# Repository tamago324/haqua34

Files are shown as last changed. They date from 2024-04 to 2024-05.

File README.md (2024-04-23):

# haqua34

* gku34 を割ったキーボード
* 割った以外は gku34 と同じ
    * 狭ピッチ
    * キーピッチが縦17mmx横18mm
    * KiCad 6 で作成
    * [horizon プラグイン](https://github.com/skarrmann/horizon/blob/5833ec133d5f8fa4f3824622efd5dbfc89d797ec/kicad-plugins/horizon-board-producer-plugin.py)を使ってボトムプレートを生成
    * choc v1 と Lofree switch 対応

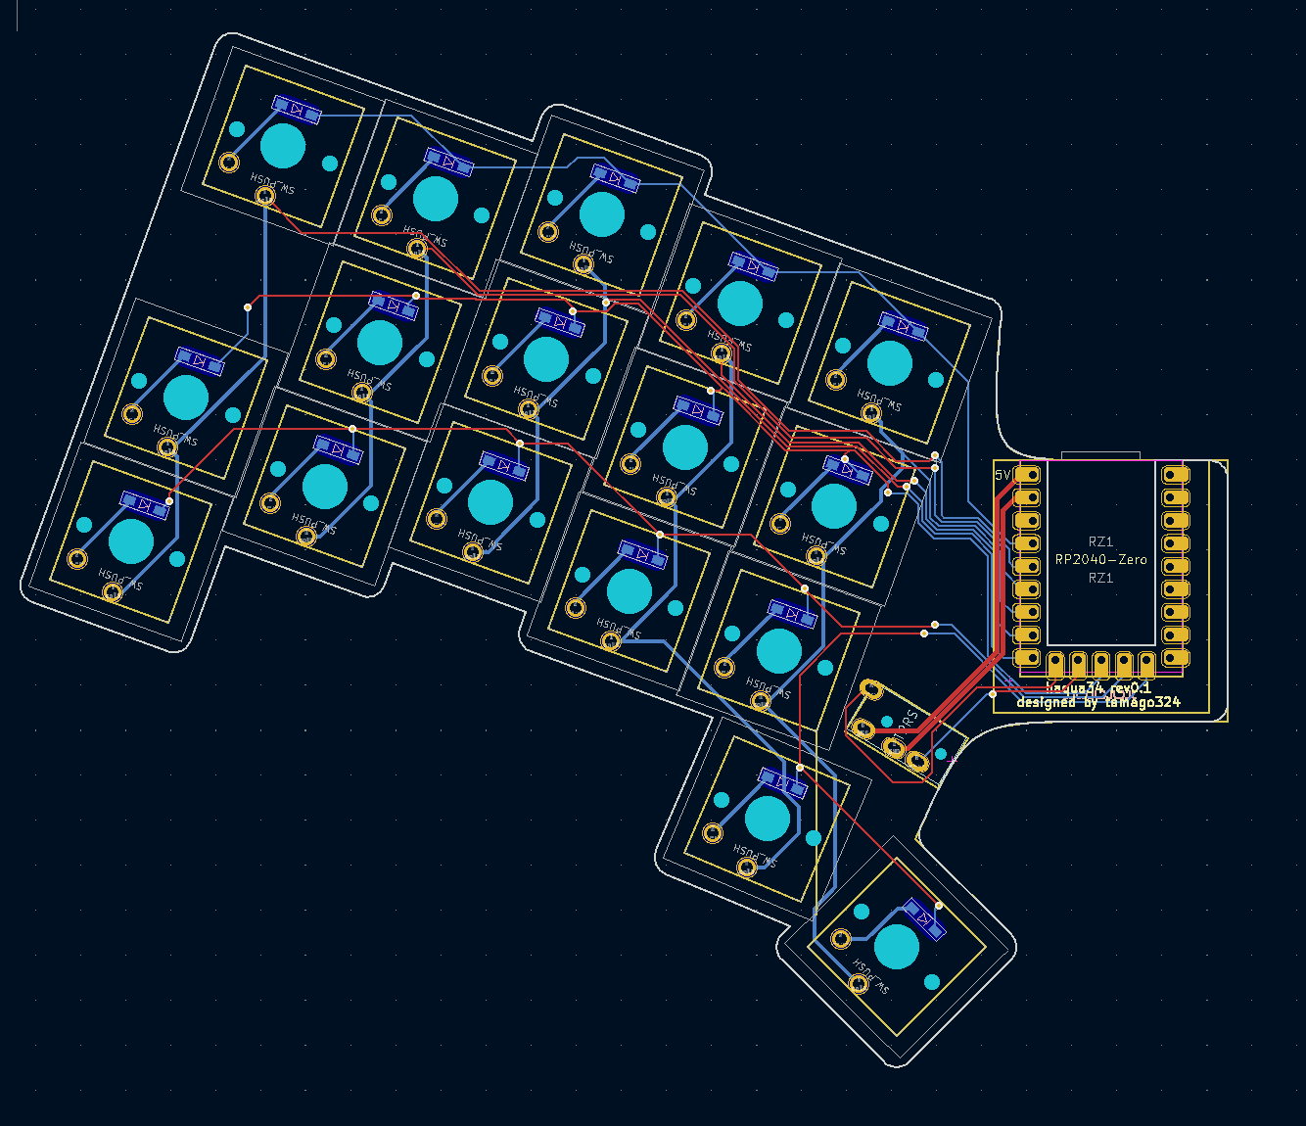
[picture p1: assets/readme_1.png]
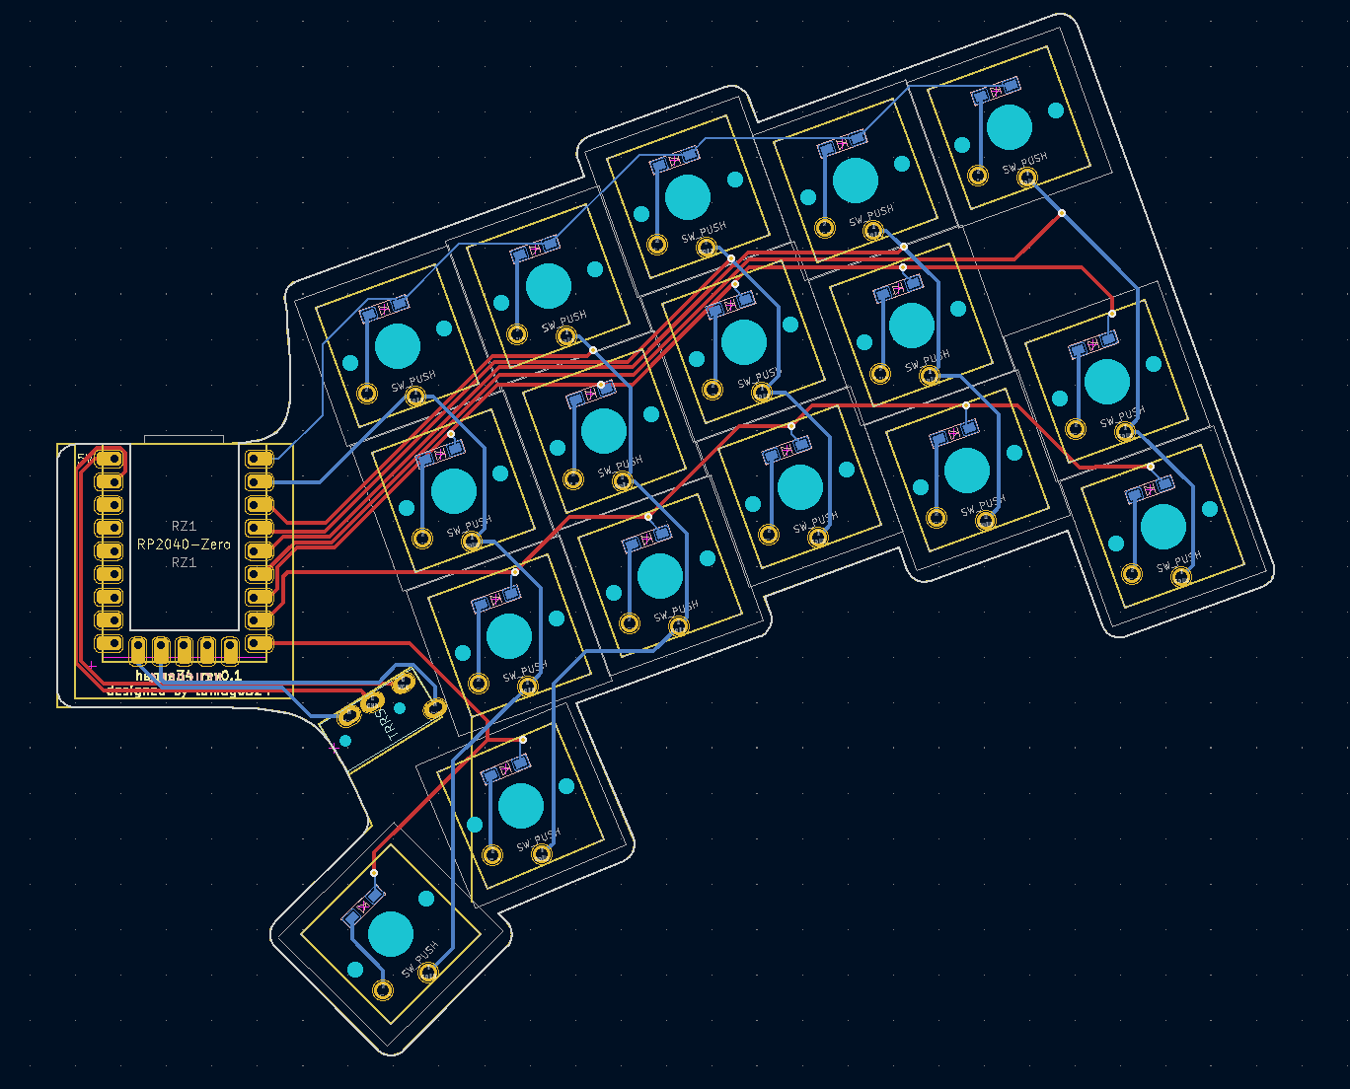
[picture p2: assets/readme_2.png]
|||
|---|---|
|left|right|

## Firmware

[keyboard-firmwares](https://github.com/tamago324/keyboard-firmwares) 内の `keybaords/haqua34`

## LICENSE

<br />この 作品 は <a rel="license" href="http://creativecommons.org/licenses/by-nc/4.0/">クリエイティブ・コモンズ 表示 - 非営利 4.0 国際 ライセンス</a>の下に提供されています。

> 表示 — あなたは 適切なクレジットを表示し、ライセンスへのリンクを提供し、変更があったらその旨を示さなければなりません。これらは合理的であればどのような方法で行っても構いませんが、許諾者があなたやあなたの利用行為を支持していると示唆するような方法は除きます。
>
> 非営利 — あなたは営利目的でこの資料を利用してはなりません。

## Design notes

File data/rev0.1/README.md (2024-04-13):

## 発注するとき (JLCPCB)

* 基板
  * main_pcb (メイン基板)
    * left: `gerbers/left_main_pcb/haqua34_left_134.025522x114.635239mm_for_JLCPCB.zip`
      * PCB Thickness: 1.6mm
      * Remove Order Number: Specify a location
    * right: `gerbers/right_main_pcb/haqua34_right_134.025517x114.635239mm_for_JLCPCB.zip`
      * PCB Thickness: 1.6mm
      * Remove Order Number: Specify a location
  * bottom_plate (ボトムプレート)
    * left: `gerbers/left_bottom_plate/haqua34_left-bottom-plate_134.025522x114.635239mm_for_JLCPCB.zip`
      * PCB Thickness: 1.6mm
      * Remove Order Number: Specify a location
    * right: `gerbers/right_bottom_plate/haqua34_right-bottom-plate_134.025517x114.635239mm_for_JLCPCB.zip`
      * PCB Thickness: 1.6mm
      * Remove Order Number: Specify a location
* トッププレート
  * left: `stl/top_plate_left.stl`
    * 3D Technology: MJF(Nylon)
    * Material: PA12-HP Nylon
    * Color: Black
  * right: `stl/top_plate_right.stl`
    * 3D Technology: MJF(Nylon)
    * Material: PA12-HP Nylon
    * Color: Black

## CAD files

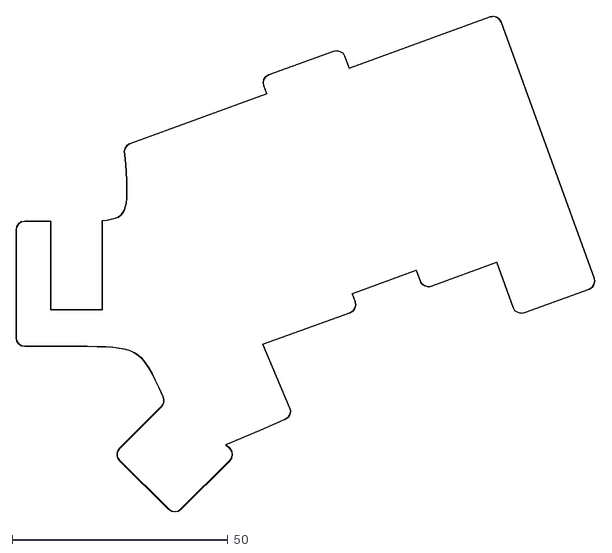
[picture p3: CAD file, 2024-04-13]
data/rev0.1/dxf/pcb_edge_right.dxf
134.3 x 115.0

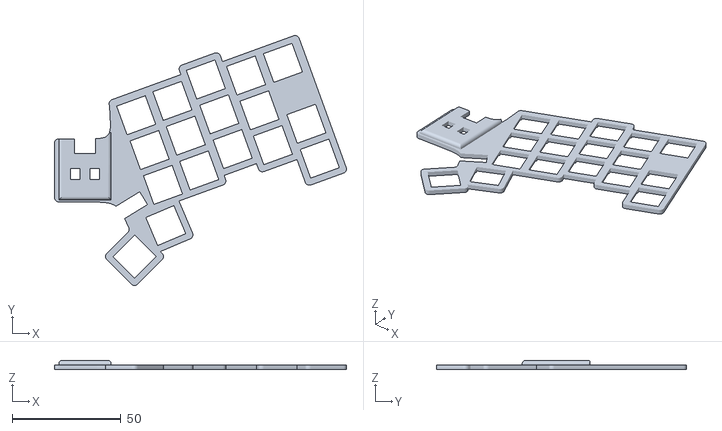
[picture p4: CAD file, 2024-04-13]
data/rev0.1/stl/top_plate_right.stl
134.0 x 114.8 x 4.20

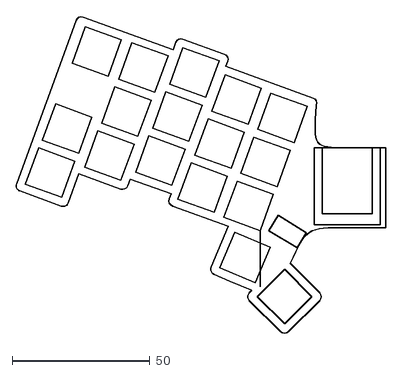
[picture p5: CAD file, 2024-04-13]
data/rev0.1/dxf/pcb_support_left.dxf
134.1 x 115.2

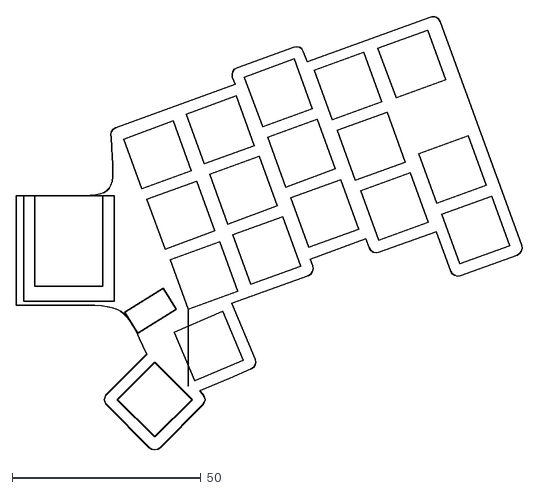
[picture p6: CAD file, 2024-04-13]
data/rev0.1/dxf/pcb_support_right.dxf
134.3 x 115.0

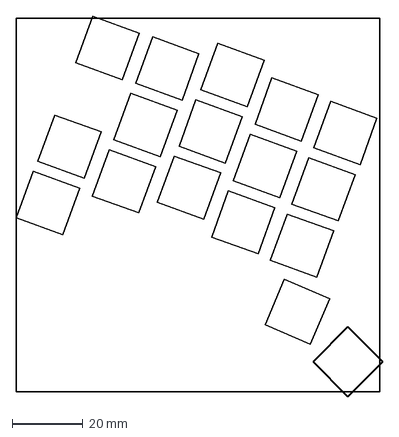
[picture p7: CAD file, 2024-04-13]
data/rev0.1/dxf/layout-base.dxf
103.9 x 107.8 mm

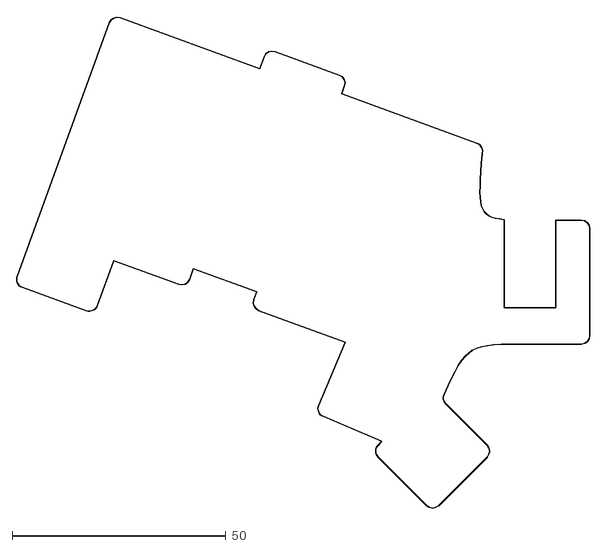
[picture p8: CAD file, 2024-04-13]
data/rev0.1/dxf/pcb_edge_left.dxf
134.1 x 115.2

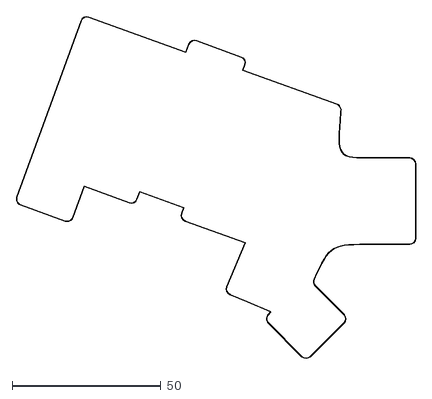
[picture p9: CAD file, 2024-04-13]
data/rev0.1/dxf/pcb_bottom_edge_left.dxf
134.1 x 115.2

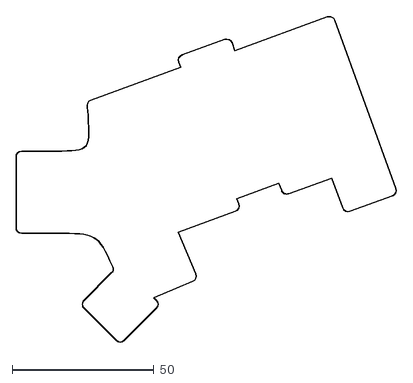
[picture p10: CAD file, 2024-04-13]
data/rev0.1/dxf/pcb_bottom_edge_right.dxf
134.3 x 115.0

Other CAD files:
data/rev0.1/stl/top_plate_left.stl

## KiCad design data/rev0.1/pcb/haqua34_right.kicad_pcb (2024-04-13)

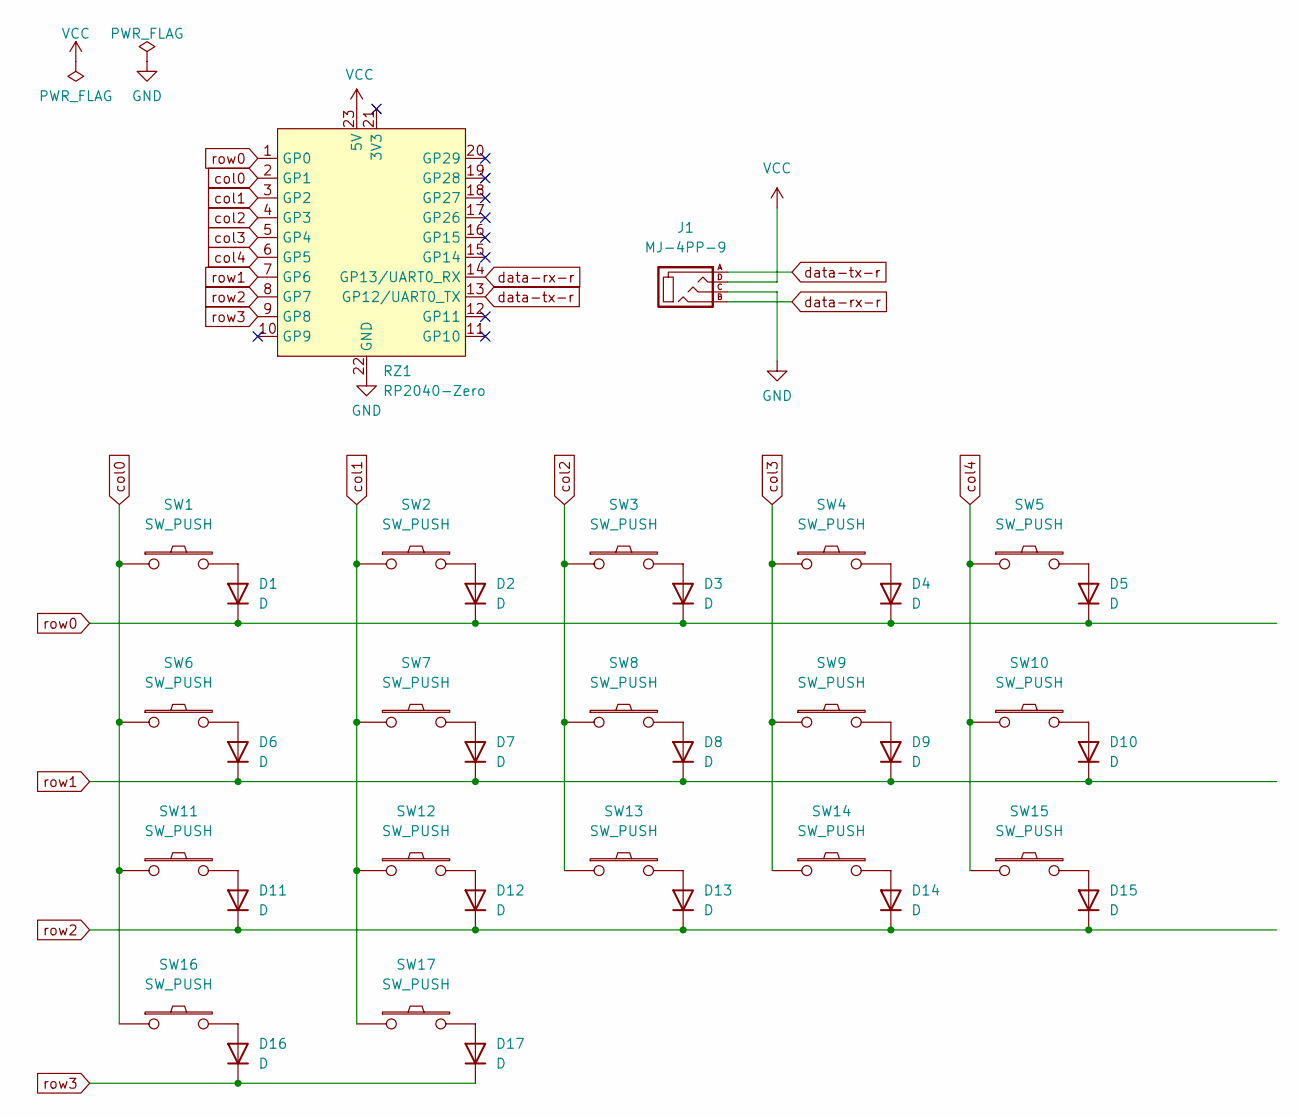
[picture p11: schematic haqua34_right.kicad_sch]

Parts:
D1, D2, D3, D4, D5, D6, D7, D8, D9, D10, D11, D12, D13, D14, D15, D16, D17: D; Diode_SMD
J1: MJ-4PP-9
RZ1: RP2040-Zero
SW1, SW2, SW3, SW4, SW5, SW6, SW7, SW8, SW9, SW10, SW11, SW12, SW13, SW14, SW15, SW16, SW17: SW_PUSH; SW_Choc_V2

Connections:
GND: J1.C, RZ1.22 (GND)
unnamed: D1.2 (A), SW1.2
unnamed: D2.2 (A), SW2.2
unnamed: D3.2 (A), SW3.2
unnamed: D4.2 (A), SW4.2
unnamed: D5.2 (A), SW5.2
unnamed: D6.2 (A), SW6.2
unnamed: D7.2 (A), SW7.2
unnamed: D8.2 (A), SW8.2
unnamed: D9.2 (A), SW9.2
unnamed: D10.2 (A), SW10.2
unnamed: D11.2 (A), SW11.2
unnamed: D12.2 (A), SW12.2
unnamed: D13.2 (A), SW13.2
unnamed: D14.2 (A), SW14.2
unnamed: D15.2 (A), SW15.2
unnamed: D16.2 (A), SW16.2
unnamed: D17.2 (A), SW17.2
VCC: J1.D, RZ1.23 (5V)
col0: RZ1.2 (GP1), SW1.1, SW6.1, SW11.1, SW16.1
col1: RZ1.3 (GP2), SW2.1, SW7.1, SW12.1, SW17.1
col2: RZ1.4 (GP3), SW3.1, SW8.1, SW13.1
col3: RZ1.5 (GP4), SW4.1, SW9.1, SW14.1
col4: RZ1.6 (GP5), SW5.1, SW10.1, SW15.1
data-rx-r: J1.B, RZ1.14 (GP13/UART0_RX)
data-tx-r: J1.A, RZ1.13 (GP12/UART0_TX)
row0: D1.1 (K), D2.1 (K), D3.1 (K), D4.1 (K), D5.1 (K), RZ1.1 (GP0)
row1: D6.1 (K), D7.1 (K), D8.1 (K), D9.1 (K), D10.1 (K), RZ1.7 (GP6)
row2: D11.1 (K), D12.1 (K), D13.1 (K), D14.1 (K), D15.1 (K), RZ1.8 (GP7)
row3: D16.1 (K), D17.1 (K), RZ1.9 (GP8)

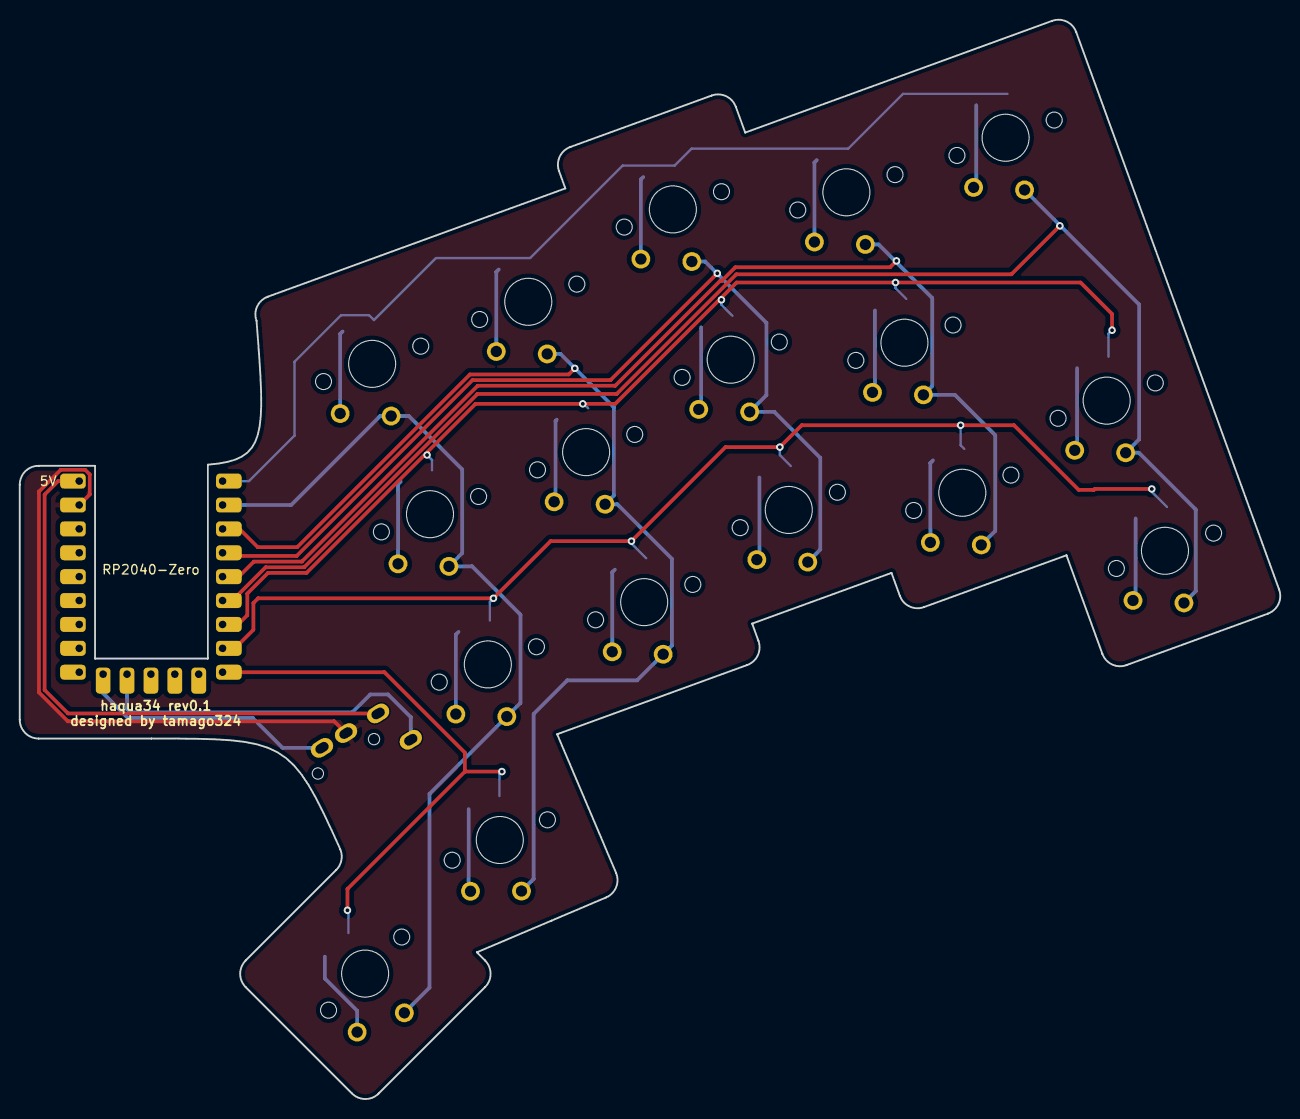
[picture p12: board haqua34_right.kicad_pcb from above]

Board: 2 copper layers, 134.0 x 114.8 mm, 36 parts (0 on the bottom side), 30 nets.

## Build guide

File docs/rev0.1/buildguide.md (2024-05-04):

# haqua34 ビルドガイド

天キーで余り基板をもらっていただきありがとうございます。  
文章のみになりますが、ビルドガイドになります。

写真については、[gku34](https://github.com/tamago324/gku34/blob/master/docs/rev0.3/buildguide.md) のビルドガイドを見ていただけると助かります。

<details><summary>目次</summary><div>

* [キットに含まれるもの](#キットに含まれるもの)
* [キット以外に必要なもの](#キット以外に必要なもの)
* [組み立て順序の確認](#組み立て順序の確認)
* [組み立て](#組み立て)
  * [1. プレートの側面をペンで塗る](#1-プレートの側面をペンで塗るる)
  * [2. RP2040-Zero のボタンをペンで塗る](#2-rp2040-zero-のボタンをペンで塗る)
  * [3. ダイオードのはんだ付け](#3-ダイオードのはんだ付け)
  * [4. RP2040-Zero のはんだ付け](#4-rp2040-zero-のはんだ付け)
  * [5. TRRSジャック のはんだ付け](#5-trrsジャック-のはんだ付け)
  * [6. 動作確認](#6-動作確認)
  * [7. スイッチのはんだ付け](#7-スイッチのはんだ付け)
  * [8. ボトムプレートを取り付ける](#8-ボトムプレートを取り付ける)
  * [9. ゴム足を取り付ける](#9-ゴム足を取り付ける)
  * [10. キーキャップを取り付ける](#10-キーキャップを取り付ける)
  * [11. キーマップの変更](#11-キーマップの変更)
* [最後に](#最後に)

</div></details>

## キットに含まれるもの

| No. | 名前 | 数量 | 備考 |
|-----|---|---|---|
| 1 | PCB (左) | 1枚 | メインPCB (左) |
| 2 | PCB (右) | 1枚 | メインPCB (右) |
| 3 | ボトムプレート (左) | 1枚 | ボトムプレート (左) |
| 4 | ボトムプレート (右) | 1枚 | ボトムプレート (右) |
| 5 | ゴム足 | 12個 | [Amazon](https://amzn.asia/d/dPdWZld)で購入できます。 |
| 6 | 両面テープ (5mm幅) | - | PCBとボトムプレートを張り合わせるために使用。 <br>[Amazon](https://amzn.asia/d/8XeKmsn)で購入できます。 |

## キット以外に必要なもの

| 名前 | 数量 | 備考 |
|---|---|---|
| トッププレート (左) | 1枚 | JLCPCBで製造してもらった3Dプリント製のトッププレート |
| トッププレート (右) | 1枚 | JLCPCBで製造してもらった3Dプリント製のトッププレート |
| ダイオード | 34個 + 予備 | [遊舎工房](https://shop.yushakobo.jp/collections/all-keyboard-parts/products/a0800di-02-100)で購入できます。 |
| RP2040-Zero | 2個 |[TALP KEYBAORD](https://talpkeyboard.net/items/640ea9f3072c3c538731c515) などで購入できます。 |
| TRRSジャック | 2個 | [TALP KEYBOARD](https://talpkeyboard.net/items/5fa25a06da019c17f0664dc7)で購入できます。 |
| ピンヘッダ | - | RP2040-Zero をまっすぐはんだ付けするために使用するピンヘッダ (※ なくても組み立ては可能ですが、あったほうがまっすぐ半田付けできるため、あると良いです。) |
| キーキャップ | 34個 | choc v1用、またはMX用キーキャップ<br>Lofreeスイッチを取り付ける場合、Junana MX キーキャップがおすすめです。([1U 凹形](https://booth.pm/ja/items/5551574)、[1U 凸形](https://booth.pm/ja/items/5551877))  |
| キースイッチ | 34個 | choc v1スイッチ、または [Lofree スイッチ](https://www.lofree.co/products/lofree-x-kailh-full-pom-low-profile-switches) |
| USBケーブル | 1個  | Type-C の USBケーブル |

### トッププレートについて

トッププレートは JLCPCB に製造してもらう必要があります。  
輸送会社を OCS にすると送料が安くなるのでオススメです。  
トッププレートは左右で異なるため、それぞれ1つずつ発注してください。  

* left: `data/rev0.1/stl/top_plate_left.stl`
  * 3D Technology: MJF(Nylon)
  * Material: PA12-HP Nylon
  * Color: Black
* right: `data/rev0.1/stl/top_plate_right.stl`
  * 3D Technology: MJF(Nylon)
  * Material: PA12-HP Nylon
  * Color: Black

また、発注する際に `There might be damage risks when printing, are you able to afford the risks?` のような確認があった場合は `Yes` を選択してください
この確認は注文履歴画面で表示される可能性があります

## 組み立て順序の確認

1. プレートの側面をペンで塗る
2. RP2040-Zero のボタンをペンで塗る
3. ダイオードのはんだ付け
4. RP2040-Zero のはんだ付け
5. TRRSジャック のはんだ付け
6. 動作確認
7. スイッチのはんだ付け
8. ボトムプレートを取り付ける
9. ゴム足を取り付ける
10. キーキャップを取り付ける
11. キーマップの変更

## 組み立て

### 1. プレートの側面をペンで塗る

PCB と ボトムプレートの側面を[ポスカ](https://amzn.asia/d/1ZZTGt9)などのペンで塗ります。

### 2. RP2040-Zero のボタンをペンで塗る

RP2040-Zero のボタンを[マッキー](https://amzn.asia/d/gaXAFb8)などのペンで塗ります。

これをすることにより、トッププレートを合わせたときに真っ黒になります。

### 3. ダイオードのはんだ付け

PCBの裏にダイオードを34個はんだ付けします。  
「PCBのシルクの線」と「ダイオードの線」が一致するようにはんだ付けします。  
はんだごての温度は320℃くらいに設定し作業します。  

片側に予備ハンダを行い、
ピンセットを使用して、はんだ付けを行い、
もう片方もはんだ付けします。

すべてのダイオードのはんだ付けが終わったら、すべてのダイオードが同じ向きになっていることを確認してください。

### 4. RP2040-Zero のはんだ付け

「PCB の表面の 5V」が「RP2040-Zero の 5V」にあうように合わせます。  
ピンヘッダを RP2040-Zero と PCB に刺して、まっすぐなるように合わせます。  
RP2040-Zero の角を4箇所はんだ付けをし、浮いていないことを確認してから、すべてをはんだ付けします。

### 5. TRRSジャック のはんだ付け

トッププレートで数か所スイッチをはめて (半田付けではなく、はめるだけ)、TRRSジャックの半田付けする位置を確認します。  
位置が決まったら、テープなどでTRRSジャックを固定し、半田付けをします。

### 6. 動作確認

#### ファームウェアの書き込み

[こちら](https://github.com/tamago324/keyboard-firmwares)で `haqua34:via` のファームウェアを作成します。

RP2040-Zero の左側のボタンを押しながら、USB を接続し、
新しいデバイスとしてファイルエクスプローラに表示されたデバイスに、ダウンロードしたファイルををコピーします。コピーが完了すると、デバイスが切断されます。
デバイスが切断されたら、ファームウェアの書き込みが完了です。

#### 入力の確認

**XXX: TRRSケーブルを左右で接続してから、USBケーブルを指してください。**

[Remap](https://remap-keys.app/) にアクセスし、`START REMAP FOR YOUR KEYBOARD` ボタンをクリック

`+KEYBAORD` をクリックし、表示された `haqua34` を選択し、`接続` をクリック

Import JSON の画面で、 [remap.json](https://github.com/tamago324/keyboard-firmwares/blob/master/keyboards/haqua34/keymaps/via/remap.json) をインポートします。

`Test Matrix Mode` をクリックし、入力の確認を行う。

スイッチのピンの穴をピンセットでショートさせることで入力を確認します。

### 7. スイッチのはんだ付け

トッププレートとPCBを合わせて、PCBの表からスイッチを差し込み、裏からスイッチをはんだ付けします。
はんだごての温度は320℃くらいに設定し作業します。

ボトムプレートを張り付ける前に念のため、再度 Remap で入力の確認をしておきます。  
もし、入力がおかしい場合、ダイオードやスイッチの足にはんだごてをあてて、再度確認します。

### 8. ボトムプレートを取り付ける

両面テープをボトムプレートに貼り付け、PCBとボトムプレートがずれないように貼り付けます。

両面テープの貼る面は、よく確認してから貼ってください。

### 9. ゴム足を取り付ける

ボトムプレートにゴム足を取り付けます。

### 10. キーキャップを取り付ける

キーキャップを取り付けます。

### 11. キーマップの変更

[keyboard-firmwares](https://github.com/tamago324/keyboard-firmwares) でファームウェアを作成し、変更可能です。

## 最後に

組み立てありがとうございました！

感想などありましたら、SNS などでつぶやいていただけると嬉しいです。

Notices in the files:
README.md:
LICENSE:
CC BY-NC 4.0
